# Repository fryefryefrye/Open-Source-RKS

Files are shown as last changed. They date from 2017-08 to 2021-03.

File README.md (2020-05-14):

# Open-Source-RKS
### What is a RKS system
RKS as the Remote keyless system. It's a proximity system that is triggered if a key is within a certain distance. <br> 
Widely used in modern vehicles. It's very convenient to Entry your car when you have RKS system. <br> 
You do not need take out of your key, just walk to your car with the key in your pocket, then you can open the door.<br>

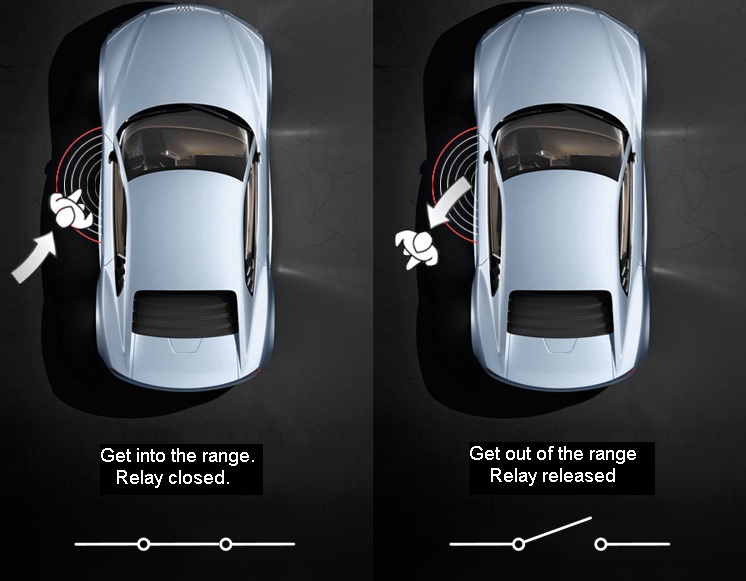
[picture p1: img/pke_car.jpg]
 <br>

<br> But do you want open the door of your home without take out your keys? Or equipment RKS to your old car?<br> 
I've found a solution that every electronic fans can make a RKS system at home in a very cheap price.<br> 
An iPhone without any app can be used as a wireless tag<br> 
Arduino based Controller can make you to use this system in any application if you like.<br>  
You can submit a issue or mail to me if you have any question.<br> 
<br>
## New update: Use your iPhone as a Tag.
### iPhone:
When IOS is enabling with continuity service, it will always sending BLE advertising to let other IOS device to know. But the Bluetooth MAC Address is random and changed every 15 minutes. <br>
With my another project, you can decode the random address and determined if this random address belongs to your phone.<br>
https://github.com/fryefryefrye/Decoding-Random-Bluetooth-Address/<br>
### Android:
Use "nRF Connect" APP, you can send BLE advertising with custom data.A name can be set in the advertising.<br>

## Hardware used:

iPhone; ESP32 Board; Arduino Board; nRF24L01 module

## Get IRK of your iPhone
If the IRK of an IOS device is known, the random Bluetooth address can be determined if it belongs to this device. <br>
### Use an ESP32 board and download with “iPhone/get_irk” project. It will start a BLE service. <br>
Pay attention on following settings.<br>
 <br>
### Use your iPhone install with “LightBlue” APP, find the “ESP_BLE_SECURITY” service, and connect it, the IRK will be print out. <br>
 <br>

## Receiver / Monitor BLE advertising with nRF24L01
With the help of the following project, we can Monitor BLE advertising with very cheap nRF24L01 module<br>
https://github.com/Pranavgulati/RF24BLE<br>
https://github.com/nRF24/RF24<br>
Install above two library into Arduino.<br>
Fill the IRK into the “iPhone/ReceiverController” project..<br>
Download “iPhone/ReceiverController” project into a Arduino nano board, you can Monitor BLE advertising and determine if the MAC address in the air is belong to your iPhone.<br><br>
These is only one key function you need to call to check MAC address. Everything needed for this function is in key.h file.You can use it in your other project.<br>
BOOLEAN btm_ble_addr_resolvable(BD_ADDR rpa, esp_bt_octet16_t irk)<br><br>

You can build the Arduino based BLE Monitor Just connect nRF24L01 module with Arduino follow the table.<br>

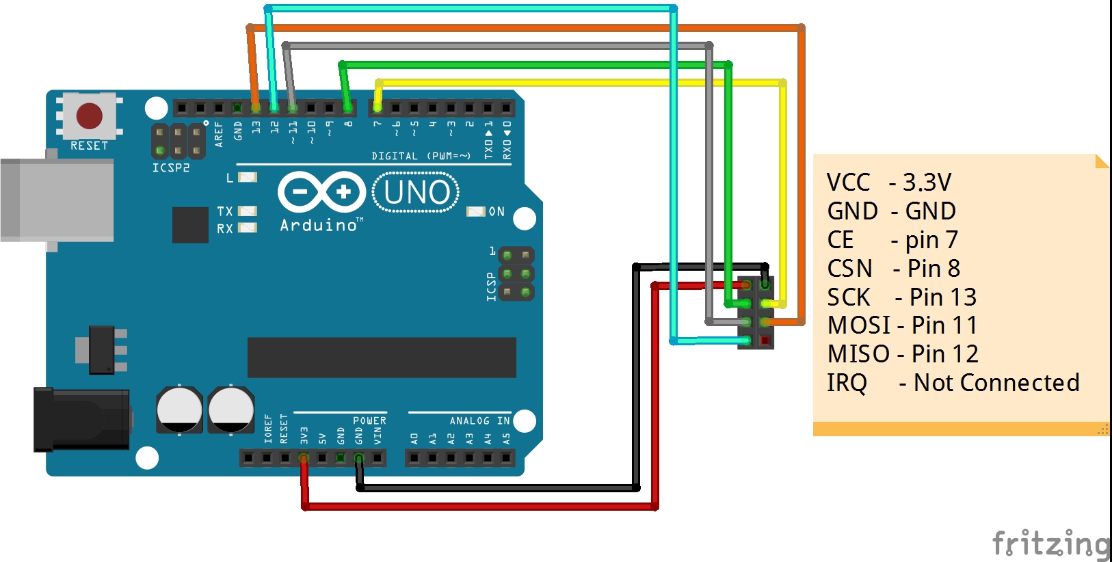
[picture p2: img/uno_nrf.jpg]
 <br>

 <br>

When you are OK to this stage, if you are walking to your reciver with your iPhone, the arduino will know you are coming.<br>
And you can write your applaction code. Like close a relay to open a door.<br>

## Old version: Released on 2016. Use Independent Wireless Tag.

### A very simple wireless Key. 

nRF24LE1 module and CR2032 battery are the only thing to make a key for RKS system. <br>
nRF24LE1 is Ultra-low Power Wireless System On-Chip Solution.<br>
An 8051 compatible MCU is attached in it. So one chip is enough.<br>
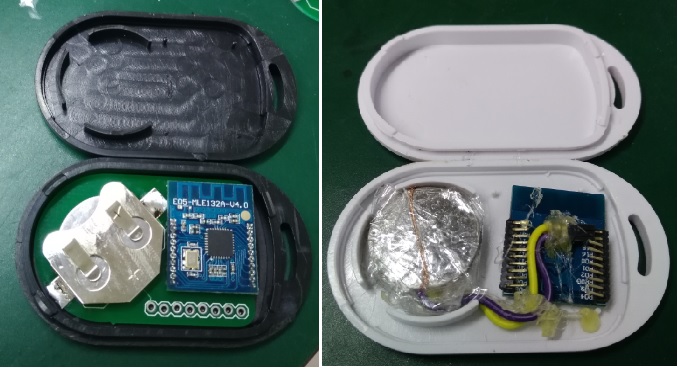
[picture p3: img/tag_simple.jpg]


### Arduino based Controller

An Arduino equipment with a nRF24L01 module, can receive the data from the key nearby.<br> 
Arduino based Controller is very easy to program, and you can make any application if you wish base on this RKS system.<br> 
In This example, a relay will be used as the output. <br> 
When key goes close in about 2 meters, the relay closed.<br> 
When key goes far away, the relay will be disconnect.<br> 
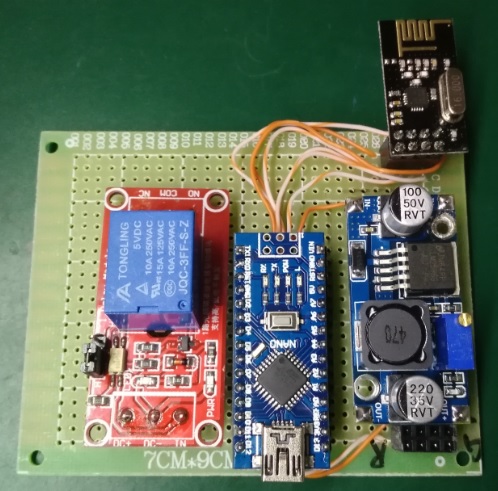
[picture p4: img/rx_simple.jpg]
.

### How they made?
* Make the Tag/Key/Transmitter

First you need program the nRF24LE1 use a Programmer.<br>
After that, just connect 2 cables from battery to power on the nRF24LE1 module is OK.<br>
All the needles on the module can be cut to short to fit in the thin case.<br>
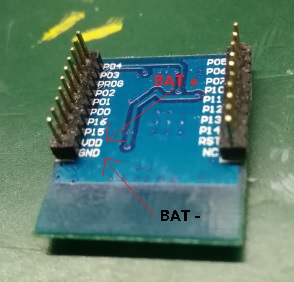
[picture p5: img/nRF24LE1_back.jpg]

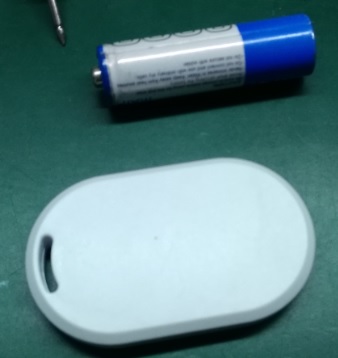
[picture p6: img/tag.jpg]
.<br>

* Make the Controller/Receiver

You can build the Arduino based Controller whatever you like. Just connect nRF24L01 module with Arduino follow the table.<br>

| PIN  | NRF24L01|Arduino UNO/NANO|Mega1280/2560|
| --- | ---| ---| ---|
|  1  |  GND  |  GND  |  GND  |
|  2  |  VCC  |  3.3V  |  3.3V  |
|  3  |  CE |  digIO 7  |  digIO 7  |
|  4  |  CSN  |  digIO 8  |  digIO 8  |
|  5  |  SCK |  digIO 13  |  digIO 52  |
|  6  |  MOSI  |  digIO 11  |  digIO 51  |
|  7  |  MISO  | digIO 12  |  digIO 50  |
|  8  |  IRQ  |  -  |-|
<br> 



<br>
This is combination I used in debug stage.<br> 

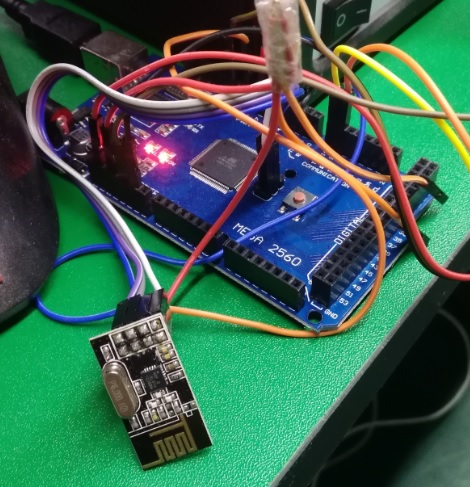
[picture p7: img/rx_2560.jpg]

<br> 
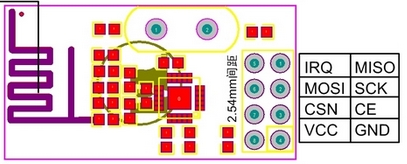
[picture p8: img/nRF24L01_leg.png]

<br>
The PCB for Controller is on the way, I will update soon.<br>

## Technical details

### Frequency hopping

The key, as an Active RFID Tag, will transmit its ID and the volt of the battery 3 times every second in 3 different channels.<br> 
The Controller, as the receiver, will listening on these 3 different channels, one channel for one second.<br> 
This will make the system more anti-interference.<br> 

### Power Consumption of the Tag

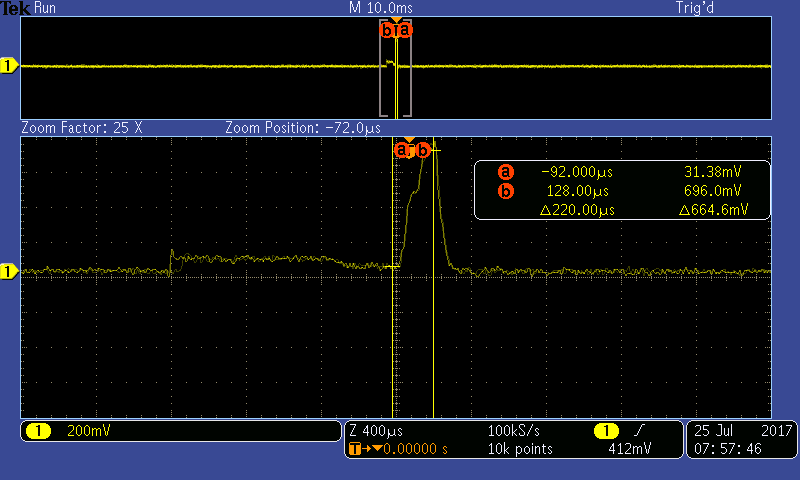
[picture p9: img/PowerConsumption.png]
<br> 

The above picture is Current sampling with a 47 Ohm resistor.<br> 

For every time of transmit. Power consumption can be estimated as:  <br> 
0.7v\*47Ohm = 32.9mA<br> 
Duration for 0.3ms <br> <br> 
Capacity of a CR2032 battery is 200 mAh.<br> 
In This example, data was transmit 3 times in every second. <br> 
Estimated life days = (200/(32.9\*(0.0003/3600)))/3/3600/24 = 281 days <br> 

## Hardware used in this project

* Tag/Key/Transmitter

### nRF24LE1 module
Reference price € 4.00<br> 
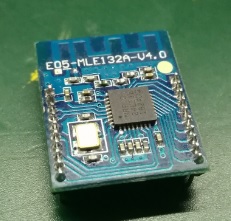
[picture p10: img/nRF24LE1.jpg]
<br> 

### Programmer for nRF24LE1
Reference price € 15.00<br> 
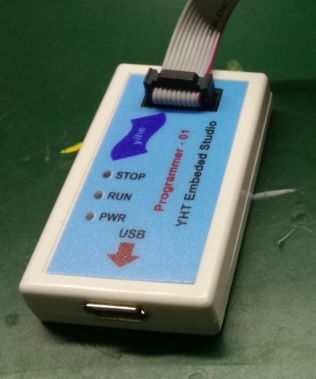
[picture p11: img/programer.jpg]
<br> 

### nRF24LE1 adapter.
Reference price € 5.00<br> 
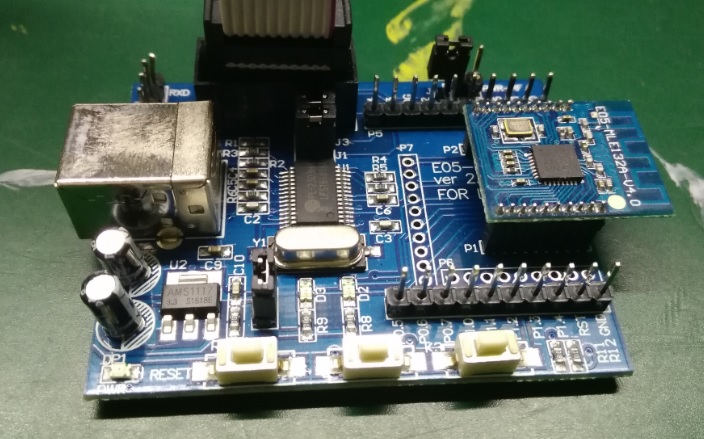
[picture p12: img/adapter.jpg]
<br> 

### CR2032 battery
Reference price € 1.00<br> 
<br> 

### Plastic case of the key
Reference price € 1.00<br> 
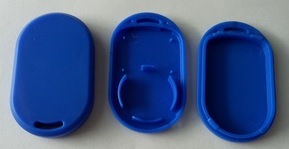
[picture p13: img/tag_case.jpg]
<br> 

### PCB of the key
Reference price € 1.00<br> 
Send the file PCB\Files_for_Factory_made\tag.cam to PCB factory, they can make it for you.<br> 
A programmer interface is placed on the PCB, you can also program the nRF24LE1 with this port after the module have been soldered on the PCB.<br> 
Or you can use any method you can do to connect the module with battery.<br> 
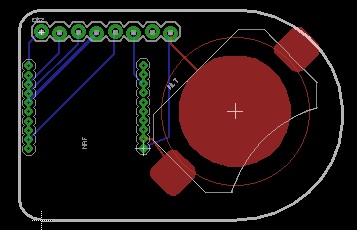
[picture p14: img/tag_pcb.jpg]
<br> 

### Battery holder in the key
Reference price € 1.00<br> 
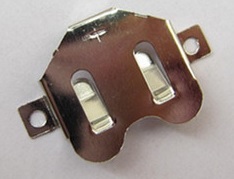
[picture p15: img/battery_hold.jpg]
<br> 

* Controller/Receiver

### Arduino
Reference price € 5.00<br> 
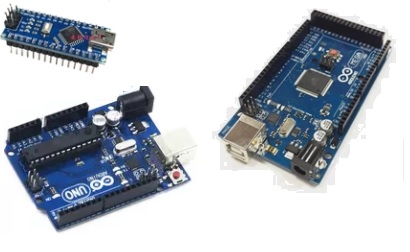
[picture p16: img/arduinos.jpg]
<br> 

### nRF24L01 module
Reference price € 2.00<br> 
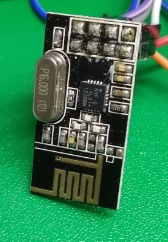
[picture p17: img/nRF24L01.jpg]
<br> 

### Integrated PCB of Controller
Reference price € 2.00<br> 
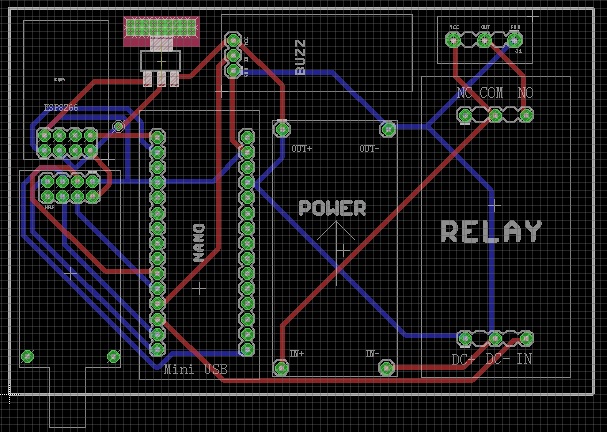
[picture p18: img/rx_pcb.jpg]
<br> 

### Buzz module
Reference price € 1.00<br> 
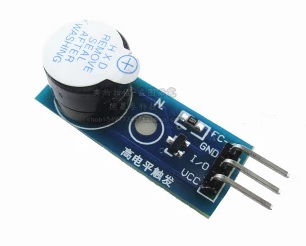
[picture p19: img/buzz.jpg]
<br> 

### Relay module
Reference price € 1.00<br> 
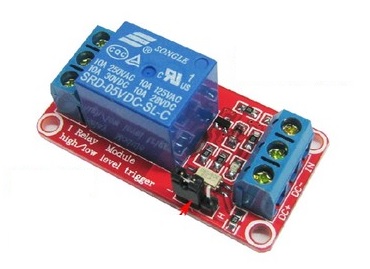
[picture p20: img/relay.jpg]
<br> 

### nRF24L01+PA module
Reference price € 4.00<br> 
A more powerful nRF24L01+PA module can get longer range and has External antenna interface. It has a compatible interface with nRF24L01 module<br> 
But it need more power on 3.3v, so a AMS1117-3.3v can be used to power this module.<br> 
<br> 

### DC-DC Converter
Reference price € 1.00<br> 
Most of cars, door locking system are using 12v. So a DC-DC Converter is needed here to power the Arduino with 5v. <br>
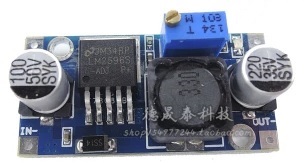
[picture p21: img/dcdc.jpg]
<br> 

## Video

## Draft

After check the ID of the key, it will drive the relay to Unlock the door for you.<br> 
When the key is get a little far away, the relay will release and the door will be locked.<br> 
You can also equipment with some power system to open the door automatically.<br>

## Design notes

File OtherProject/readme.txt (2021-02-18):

超简单DIY--制作自动授时64*32LED单色大屏时钟（开源）

落叶风大侠的WiFi LED彩屏天气万年历时钟，确实非常不错，但是门槛太高了，很多人想做，但是力不从心啊。

我这边发布一个能够让更多人能够做出来的大屏时钟，有以下优点。

1：程序简单，只有一个Arduino工程，插上USB即可下载。
2：硬件简单，只需要两个元件，焊接10来根线，无需电路板。
3：成本便宜，LED板全新价格也就30元，再加一块10元的ESP8266 D1板就够了。
3：联网能力，ESP8266有联网能力，我开源的程序，已经做好了时间同步。以后可以继续扩展天气预报等功能。
4：中文显示，我开源的程序，已经集成了16*16中文字库，可以直接用UTF-8编码显示。显示天气，万年历等超级方便。
5：OTA能力，除了第一次需要用USB下载，以后可以使用WiFi下载程序了，无需把墙上的时钟拿下来。

所需的两个元件，淘宝采购：
这种LED屏有红色单色的，也有红绿双色的。但是ESP8266的IO口有限，我只能搞定一种颜色。如果买红绿双色，只能用改变接线的方式，永久性的改变颜色，可以显示绿色，也可以显示橙色。

打开源代码，找到如下部分：
#define RowA D8    	//行信号,驱动138  
#define RowB D7
#define RowC D6
#define RowD D5
#define STB D2         //595 刷新显示  SS  
#define CLK D1         //时钟    SCK  
#define OE D0 			//  使能  
#define R1 D4          //上半屏列信号输出    
#define R2 D3          //下半屏列信号输出    

照此定义，把LED屏和ESP8266 D1 板焊在一起。另外把5v供电线也给焊上。板上插一根USB线备用。

硬件完工，下面搞软件：

Arduino的开发环境，下载下来后，需要在“开发板管理器”里面加入ESP8266的支持。
另外在“库管理器中”下载一个“u8g2”这是一个包含中文字库的显示屏驱动。

最后一步，修改源代码中的wifi名和密码，然后通过USB下载，就搞定啦。

源代码在此：
https://github.com/fryefryefrye/Open-Source-RKS/tree/master/OtherProject/clock

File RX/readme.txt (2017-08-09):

This is an arduino project.

It can be download to:
Arduino 2560
Arduino nano
Arduino uno
......

RX.ino

It's a very basic application. If it get data from Tag, the relay of the door will closed.

RX_315.ino

It's a bit advanced application. If it get data from Tag, it will send out remote control single like your car key, to Ulock or Lock your car.
A RF_TX module of 433/315 Mhz is needed. Also you must know protocol of your car key.

rx_web.ino

It's another bit advanced application. It works like the first door controller, but it will record all entry log with the  volt of the battery.
With a ESP8266, it also works as a web server, you can open the address of the controller, check the logs.

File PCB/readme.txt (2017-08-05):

PCB was made by EAGLE-7.6.0.
Files in following foler can be send to Factory to make the PCB.
\PCB\Files_for_Factory_made

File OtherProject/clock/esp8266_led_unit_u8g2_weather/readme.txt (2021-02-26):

[Arduino] 超简单DIY~制作64*32 LED单色大屏天气预报（开源） 

上次发的大屏时钟。

[Arduino] 超简单DIY~制作自动授时64*32 LED单色大屏时钟（开源） 
https://www.mydigit.cn/forum.php?mod=viewthread&tid=235844

代码内置了中文字库，但是还没用上，今天折腾了一下，把天气预报的部分也搞好了，让新手也能简单上路，搞个带天气预报的时钟。

本次硬件还是和上次的一样，只做了些软件的修改。
需要自己去"心知天气"申请一个帐号，获得api-key。然后填到代码开头的相应位置。注意后面城市名，我写的是nanjing，个人自己修改好。有重名的话，去心知天气网站找到自己城市的代号填上去，更准确。

我写的屏幕布局只是个例子，自己可以随意修改。在代码的最后部分。那些都是在屏幕上打印字符串的函数，其中两个数字参数就是屏幕的x，y坐标，根据自己需要修改试验就行了。

在我家的墙上挂的是这个，只是很久以前做的，不管是硬件还是软件都很烂，就不分享了。怕麻烦的同学直接做两个，并排放就可以了。

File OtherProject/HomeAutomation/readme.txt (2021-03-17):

介绍我家的智能家居系统（原理细节详细介绍，尽量部分关键部分开源）

我家这套智能家居系统已经运行了很多年了，自我感觉不错，给大家分享一下。
也是断断续续开发了很多年，一下子不可能讲的很清楚，有兴趣的同学可以提问，我继续回答。

早年买了一些所谓的智能家居硬件设备，最后得到的是手机里一大堆APP，以及薛定谔状态的可用性。最后决定全部自己开发。

现在这套系统的优点：
1：全部自己开发，需要新功能，实现新想法，只要是可行的，就能做出来。
2：大部分功能通过局域网实现，不依赖互联网。只要家里有电，就能正常运行大部分功能（外网控制除外）
3：控制界面只有一个，一眼看清所有设备状态，一键即可控制所需设备，无需在一堆APP中，一大堆页面中翻来翻去。

整套系统主要结构如下：

1：用ESP8266作为节点，每秒发一个UDP包到树莓派服务器，包含节点采集到的数据和状态（比如：温度，湿度，灯已开，灯已关）。
2：树莓派服务器收到节点更新后，回复一个UDP命令包，包含发送给节点的控制命令（比如：开灯，关灯），并缓存节点的IP地址信息。
3：树莓派另开web服务，手机电脑均可访问，可以查看状态，也可以控制，在家通过局域网访问，不依赖互联网，在外需要做一个端口映射（申请公网IP）。
4：收到web的控制命令后，立即给节点发送命令UDP包（之前已经缓存了节点IP信息），可以做到灯一按就亮，几乎无延时。

控制界面是这样的：

控制界面的实现原理（使用Ajax更新网页里的部分文字）：
上图所示的控制界面是一个html文件，只需要加载一次。但是表格中的数据和状态都是每秒使用Ajax更新的。
流程大概是这样
a）浏览器请求 http://192.168.0.17/index   树莓派服务器直接返回一个html文件
b）html文件里面有脚本，每秒执行一次，发起请求  http://192.168.0.17/update
c）树莓派返回一串用“,”隔开的字符串。脚本会按照“,”分割，形成一个字符串数组。
d）把这个数组填个表格的相应部分。

这是html文件的一个简单的例子，我用来显示天气预报的。
https://github.com/fryefryefrye/Open-Source-RKS/tree/master/OtherProject/HomeAutomation/weatherindex.html

树莓派服务器实现原理（web服务）：

上一段已经介绍了如何使用Ajax更新网页里的部分文字，其中重要的一点就是服务器需要自动生成一串用“,”隔开的字符串。
这个就需要在树莓派上编程实现。
由于我不喜欢使用现成的web服务软件，我就自己实现了一个最简单的web服务器。
流程大概是这样
a）创建一个socket，在80端口上监听。
b）连接建立之后，一般会收到一个类似“GET /index HTTP/1.1”的请求。
c) 根据请求内容，给予适当的回复，在回复实际内容之前，发送一个http回复的head就行了
const char HttpResponseHeadSimple[]   ="HTTP/1.1 200 OK\r\nContent-Type: text/html\r\n\r\n";
d）上面那个头部，最后两个回车之后，就可以发送实际数据了，不管是一个html文件，还是“,”隔开的字符串，都可以。
e）发完就可以关闭socket,等待下一个连接请求。

树莓派服务器实现原理（UDP数据交换）：
为了定义节点与服务器交换的数据格式，我写了一个共用h文件，即被Arduino节点的程序包含，也被服务器的程序包含。
这个h文件里定义数据格式，例子如下。
struct tMeterData
{
	unsigned long DataType; //data type = 5
	unsigned long Mac[6];
	unsigned long Power;		//xx.xxxx W
	unsigned long TotalEnergy;		//xxxxxx.xx kWh
	unsigned long Volt;			//xxx.x v
	unsigned long Current;		//xxx.xxx A

};

struct tMeterCommand
{
	unsigned long Triger; 
	unsigned long On
};

这是一个交流电功率计的数据格式的例子，所有的数据都是用的4字节长整型，以免不同的平台的字节序问题。
上传数据的第一组是数据类型，用来检测是哪一种设备发来的，其他的就是数据更新。
下发的命令是每秒都会回复的，当作心跳包。但是没有实际操作请求的时候，triger = false。
如果真的要操作，就设为True，表示这是一个需要执行的命令，节点就会根据下发的数据执行相应的操作。

不同功能的节点，其实很多，我介绍几个大家比较能用的着的（待续）：

1：房间灯光控制器

2：房间空调控制器

3：用电功率监视器

4：挂在家里的天气预报/时钟

5：电动车充电控制器

不同功能的界面：

1：家门口控制器

2：挂在公司的天气预报

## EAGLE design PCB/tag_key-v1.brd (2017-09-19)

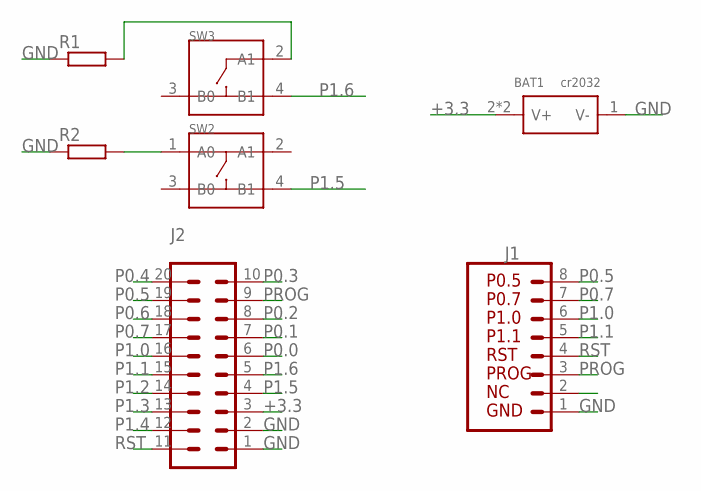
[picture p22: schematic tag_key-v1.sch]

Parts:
BAT1: cr2032; SEEED-OPL-CONNECTOR_BAT2P-20.32-CR2032
J1: SPARKFUN-CONNECTORS_CONN_08"; SPARKFUN-CONNECTORS_1X08
J2: SPARKFUN-CONNECTORS_CONN_11_1.27MM; SPARKFUN-CONNECTORS_1X11-1.27MM
R1, R2: RESISTOR_R-EU_M0805; RESISTOR_M0805
SW2: SEEED-OPL-SWITCH_SMD-BUTTON(4P-6.0X6.0X7.5MM); SEEED-OPL-SWITCH_SW4-SMD-4.5-6.0X6.0X7.5MM
SW3: SEEED-OPL-SWITCH_SMD-BUTTON(4P-6.0X6.0X3LEGM); SEEED-OPL-SWITCH_SW4-SMD-4.5-6.0X6.0_3LEG

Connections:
+3.3: BAT1.2 (V+), BAT1.3 (V+), J2.3
GND: BAT1.1 (V-), J1.1, J2.1, J2.2, R1.1, R2.1
unnamed: R2.2, SW2.1 (A0)
unnamed: R1.2, SW3.2 (A1)
P0.0: J2.6
P0.1: J2.7
P0.2: J2.8
P0.3: J2.10
P0.4: J2.20 (11)
P0.5: J1.8, J2.19 (12)
P0.6: J2.18 (13)
P0.7: J1.7, J2.17 (14)
P1.0: J1.6, J2.16 (15)
P1.1: J1.5, J2.15 (16)
P1.2: J2.14 (17)
P1.3: J2.13 (18)
P1.4: J2.12 (19)
P1.5: J2.4, SW2.4 (B1)
P1.6: J2.5, SW3.4 (B1)
PROG: J1.3, J2.9
RST: J1.4, J2.11 (20)

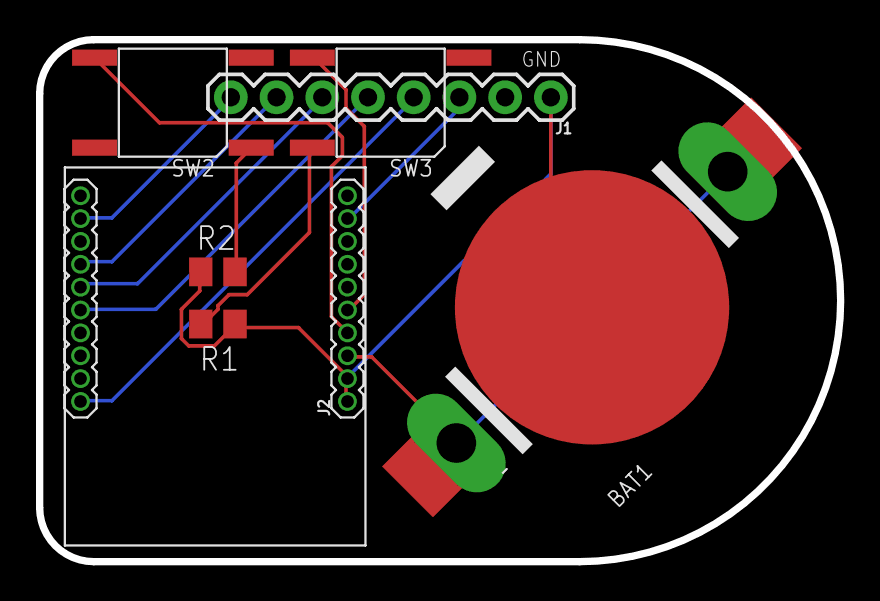
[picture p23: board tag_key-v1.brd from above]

Board: 2 copper layers, 44.5 x 29.0 mm, 7 parts (0 on the bottom side), 12 nets.

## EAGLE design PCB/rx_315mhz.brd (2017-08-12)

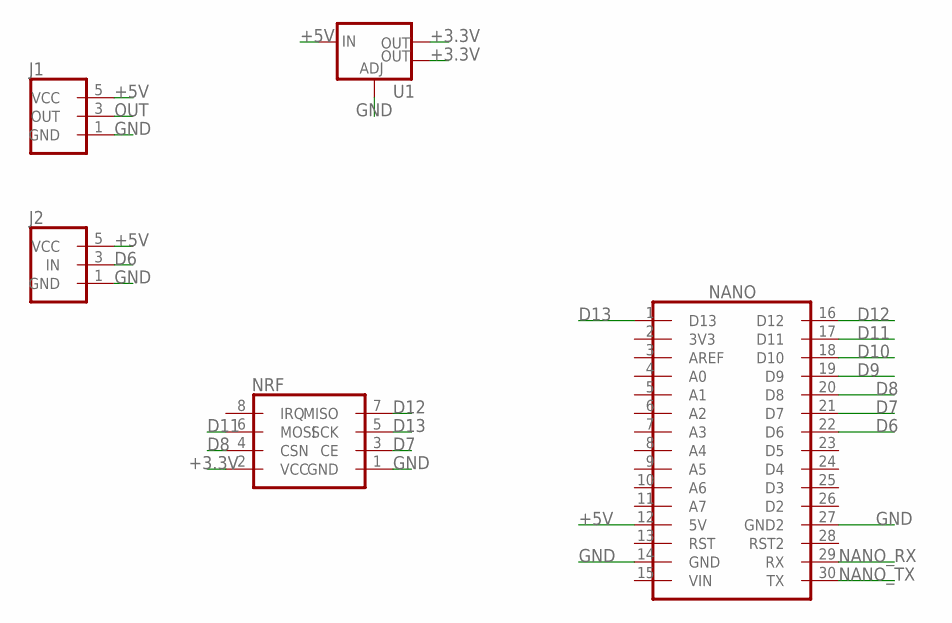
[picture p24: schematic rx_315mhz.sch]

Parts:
J1: OUT_HEAD_3BIG; OUT_HEAD_3_BIG
J2: 315MHZ_TX
NANO: ARDUINO_NANO
NRF: NRF24L01_MODULE; NRF24L01
U1: V_REG_LM1117SOT223; SOT223

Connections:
+3.3V: NRF.2 (VCC), U1.2 (OUT), U1.4 (OUT)
+5V: J1.5 (VCC), J2.5 (VCC), NANO.12 (5V), U1.3 (IN)
D6: J2.3 (IN), NANO.22 (D6)
D7: NANO.21 (D7), NRF.3 (CE)
D8: NANO.20 (D8), NRF.4 (CSN)
D9: NANO.19 (D9)
D10: NANO.18 (D10)
D11: NANO.17 (D11), NRF.6 (MOSI)
D12: NANO.16 (D12), NRF.7 (MISO)
D13: NANO.1 (D13), NRF.5 (SCK)
GND: J1.1 (GND), J2.1 (GND), NANO.14 (GND), NANO.27 (GND2), NRF.1 (GND), U1.1 (ADJ)
NANO_RX: NANO.29 (RX)
NANO_TX: NANO.30 (TX)
OUT: J1.3 (OUT)

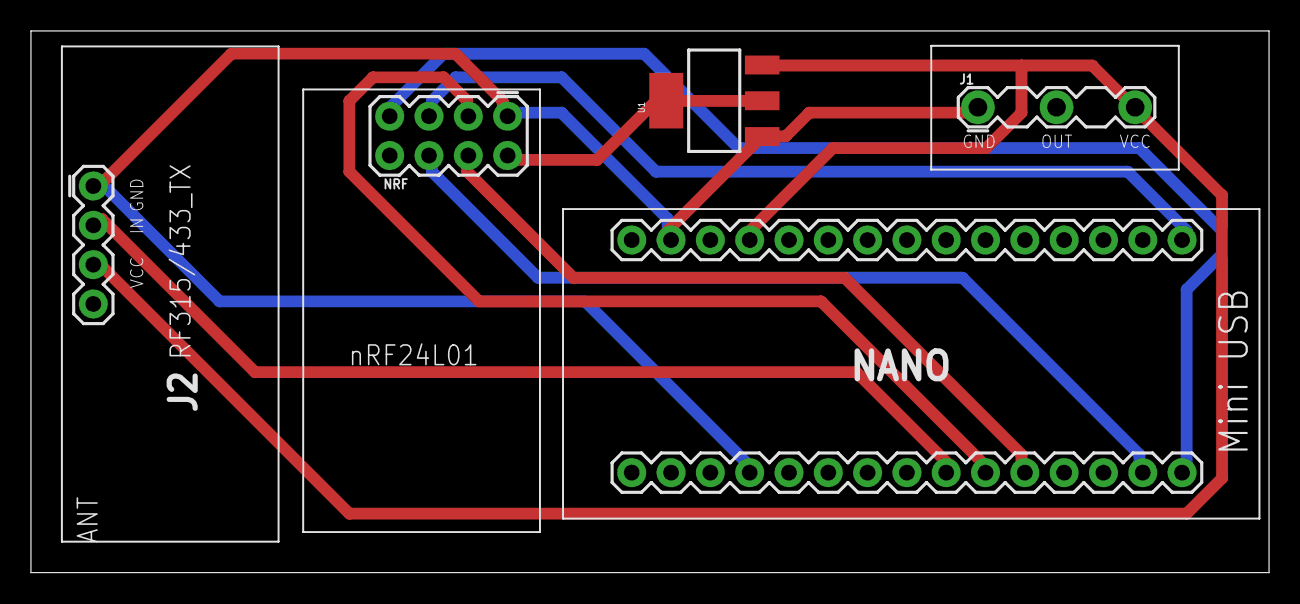
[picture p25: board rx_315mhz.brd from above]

Board: 2 copper layers, 80.0 x 35.0 mm, 5 parts (0 on the bottom side), 9 nets.

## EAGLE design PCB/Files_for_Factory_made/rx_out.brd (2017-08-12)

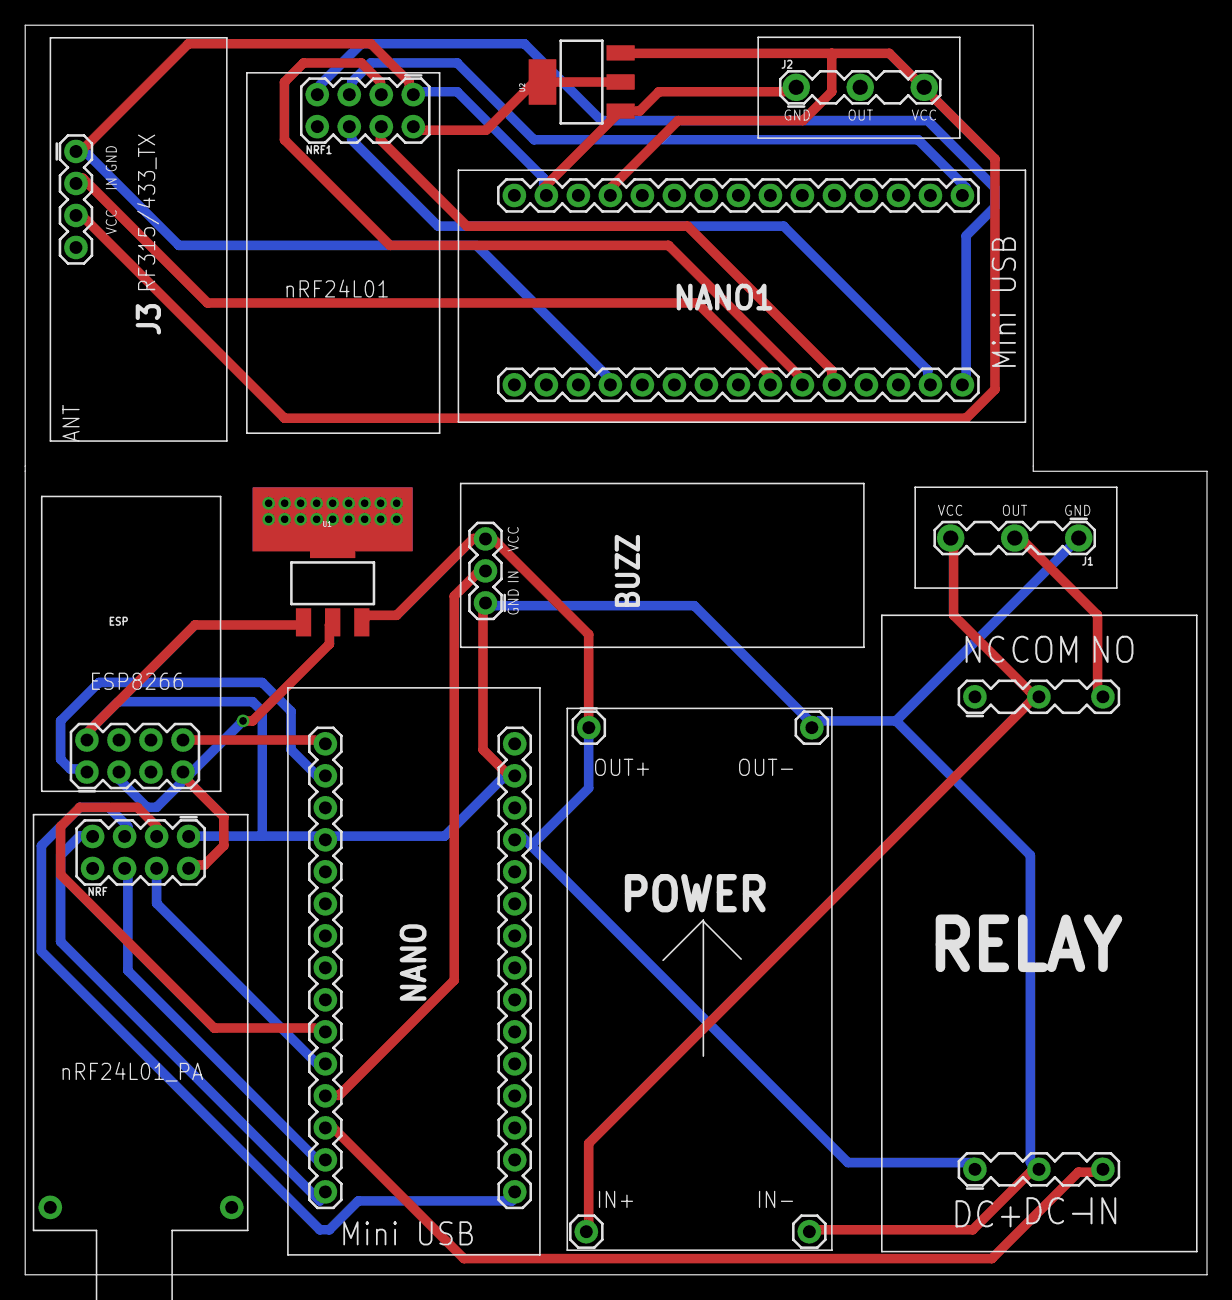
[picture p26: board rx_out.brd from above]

Board: 2 copper layers, 93.8 x 99.2 mm, 13 parts (0 on the bottom side), 23 nets.

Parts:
BUZZ: BUZZ_MODULE
ESP: ESP8266
J1, J2: OUT_HEAD_3_BIG
J3: 315MHZ_TX
NANO, NANO1: ARDUINO_NANO
NRF: NRF24L01_PA
NRF1: NRF24L01
POWER: POWER_REDUCE
RELAY: RELAY_MODULE
U1, U2: SOT223

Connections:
+3.3V: ESP.3, ESP.7, NRF.2, U1.2, U1.4
+3.3V1: NRF1.2, U2.2, U2.4
+5V: BUZZ.5, NANO.12, POWER.1, RELAY.1, U1.3
+5V1: J2.5, J3.5, NANO1.12, U2.3
+12V: J1.5, POWER.3, RELAY.5
D1: NANO1.17, NRF1.6
D2: NANO1.20, NRF1.4
D3: NANO1.1, NRF1.5
D4: NANO1.21, NRF1.3
D5: NANO1.16, NRF1.7
D7: NANO.21, NRF.3
D8: NANO.20, NRF.4
D9: BUZZ.3, NANO.19
D10: NANO.18, RELAY.3
D11: NANO.17, NRF.6
D12: NANO.16, NRF.7
D13: NANO.1, NRF.5
D15: J3.3, NANO1.22
GND: BUZZ.1, ESP.2, J1.1, NANO.14, NANO.27, NRF.1, POWER.2, POWER.4, RELAY.2, U1.1
GND1: J2.1, J3.1, NANO1.14, NANO1.27, NRF1.1, U2.1
NANO_RX: ESP.1, NANO.29
NANO_TX: ESP.8, NANO.30
OUT: J1.3, RELAY.6

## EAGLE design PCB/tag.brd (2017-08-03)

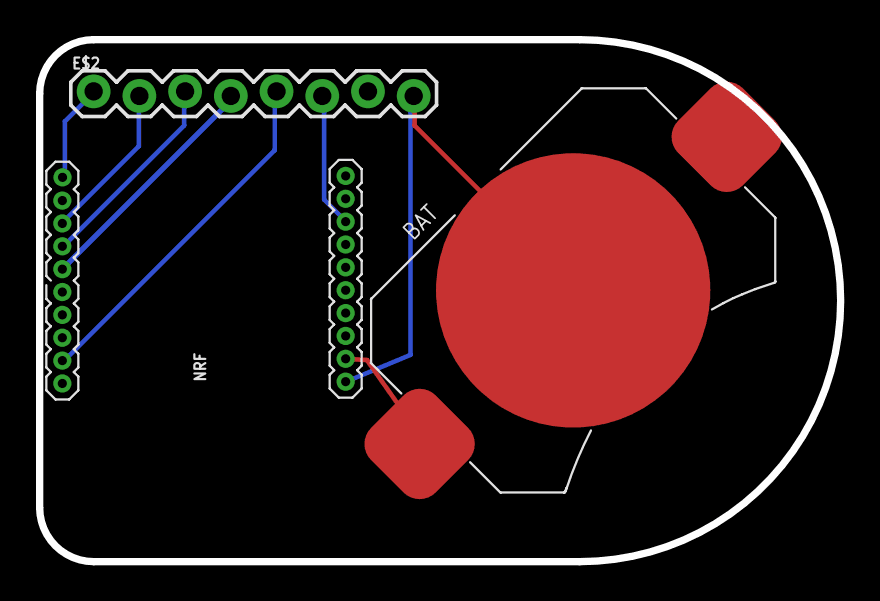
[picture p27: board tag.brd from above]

Board: 2 copper layers, 44.5 x 29.0 mm, 3 parts (0 on the bottom side), 8 nets.

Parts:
BAT: BAT2P-SMD-20.32-CR2032
E$2: 1X08_LOCK
NRF: 1X11-1.27MM

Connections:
S$1: BAT.V-, E$2.8, NRF.1
S$2: BAT.V1, NRF.2
S$3: E$2.4, NRF.14
S$5: E$2.3, NRF.16
S$8: E$2.6, NRF.8
S$12: E$2.5, NRF.19
S$14: E$2.2, NRF.18
S$15: E$2.1, NRF.11

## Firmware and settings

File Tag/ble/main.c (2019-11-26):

#include <reg24le1.h>
#include <stdint.h>
#include <stdbool.h>
#include "hal_nrf.h"
#include "hal_nrf_hw.h"
#include "hal_clk.h"
#include "hal_rtc.h"
#include "hal_delay.h"
#include "hal_adc.h"
#include "hal_wdog.h"
#include "hal_uart.h"
#include "string.h"


/*************************user modify settings****************************/
#define  TAG_ID 2


#define  TAG_TIME				10530+64*TAG_ID		//sleep time£º10530=0.3s;	32768=1s
#define  ADC_TIME				10800		//volt of BAT,   every =   ADC_TIME*TAG_TIME
#define  TX_PAYLOAD_LEN			6        	// data length
#define  TX_PACKET_LEN			TX_PAYLOAD_LEN + 16        	// data length
#define  TX_CH_NUMBER			3        	// data length       

#define  RF_POWER 		 HAL_NRF_0DBM
//HAL_NRF_18DBM,          /**< Output power set to -18dBm */
//HAL_NRF_12DBM,          /**< Output power set to -12dBm */
//HAL_NRF_6DBM,           /**< Output power set to -6dBm  */
//HAL_NRF_0DBM            /**< Output power set to 0dBm   */

/******************************************************************************/


//#define  S1    P15  // Key S1
//#define  S2    P16  // Key S2

//// The MAC address of the beacon
#define MY_MAC_0  0x60
#define MY_MAC_1  0x59
#define MY_MAC_2  0x48
#define MY_MAC_3  0x47
#define MY_MAC_4  0x46
#define MY_MAC_5  0x45

#define ANDROID		 0x42
#define IPHONE		0x40

/* Watchdog*/
#define USE_WDT   1
#define WDT_TIME  256  //2S


uint8_t   CellVoltageH;
uint8_t   CellVoltageL;
xdata bool  radio_busy;
xdata uint8_t  TxPayload[TX_PAYLOAD_LEN];
uint16_t PipeAndLen;
uint8_t CurrCH = 0;


void PrintInt16(uint16_t Counter);
void UART0_SendStr( char* str );

//xdata uint8_t _packet[TX_PACKET_LEN] = {0xBA,0x1C,0x54,0x60,0xBB,0x85,0x53,0xF3,0xC3,0xEB,0x03,0x82,0xFB,0xBA,0xBB,0xC7,0x71,0x7E,0x2D,0x01}; //maximum size of payload handled by nrf24L01 is 32
xdata uint8_t _packet_coded[TX_CH_NUMBER][TX_PACKET_LEN] = {{0xF3,0xBB,0xEC,0x1F,0xA6,0x0F,0x0C,0xA7,0xEE,0x0C,0x28,0xB2,0x96,0x6E,0x5F,0x07,0x42,0x1F,0x82,0x85}  //Len = 20 ch = 0Start LE advertizing
,{0x29,0x53,0x24,0x9E,0x80,0x91,0xED,0x5B,0x98,0x25,0x55,0xE2,0x21,0xF2,0xF3,0xC6,0xF7,0xCE,0x13,0x87}  //Len = 20 ch = 1Start LE advertizing
,{0xBA,0x1C,0x54,0x60,0xBB,0x85,0x53,0xF3,0xC3,0xEB,0x03,0x82,0xFB,0x1A,0x3B,0x47,0xD1,0x50,0xF2,0x7B}};  //Len = 20 ch = 2Start LE advertizing

uint8_t _length = 0; //length of packet filled
uint8_t _dataFieldStartPoint = 0;
xdata uint8_t chRf[] = {2,26,80} ; 
xdata uint8_t chLe[] = {37,38,39} ;

#define crc_mul 0x1021
uint16_t cal_crc(unsigned char *ptr, unsigned char len)
{
	unsigned char i;
	unsigned int crc=0;
	while(len-- != 0)
	{
		for(i=0x80; i!=0; i>>=1)
		{
			if((crc&0x8000)!=0)
			{
				crc<<=1;
				crc^=(crc_mul);
			}else{
				crc<<=1;
			}
			if((*ptr&i)!=0)
			{
				crc ^= (crc_mul);
			}
		}
		ptr ++;
	}
//	UART0_SendStr("crc:");
//	PrintInt16(crc);
//	UART0_SendStr("\r\n");
	return (crc);
}

void fill_crc(unsigned char *ptr, unsigned char stru_len)
{
	uint16_t * pSum = ((uint32_t*)(ptr+stru_len-2));
	*pSum = cal_crc(ptr,stru_len-2);
}

uint8_t  reverseBits(uint8_t input)
{
		// reverse the bit order in a single byte
		uint8_t temp = 0;
		if (input & 0x80) temp |= 0x01;
		if (input & 0x40) temp |= 0x02;
		if (input & 0x20) temp |= 0x04;
		if (input & 0x10) temp |= 0x08;
		if (input & 0x08) temp |= 0x10;
		if (input & 0x04) temp |= 0x20;
		if (input & 0x02) temp |= 0x40;
		if (input & 0x01) temp |= 0x80;
		return temp;
}
uint8_t  bleWhitenStart(uint8_t chan){
	//use left shifted one
	return reverseBits(chan) | 2;
}

void setPhone(uint8_t phone_type)
{
	//byte no.0 PDU
	uint8_t i;
	for(i=0; i<TX_CH_NUMBER; i++)
	{
		_packet_coded[i][0] = phone_type;	
	}
}
void setMAC(uint8_t m0, uint8_t m1, uint8_t m2, uint8_t m3, uint8_t m4, uint8_t m5)
{
	uint8_t i;
	for(i=0; i<TX_CH_NUMBER; i++)
	{
		//length of payload is entered in byte no.1
		_length = 2;
		_packet_coded[i][_length++] = m0;
		_packet_coded[i][_length++] = m1;
		_packet_coded[i][_length++] = m2;
		_packet_coded[i][_length++] = m3;
		_packet_coded[i][_length++] = m4;
		_packet_coded[i][_length++] = m5;
		//length should be 8 by now
		//flags (LE-only, limited discovery mode)
		_packet_coded[i][_length++] = 2;    //flag length
		_packet_coded[i][_length++] = 0x01; //data type
		_packet_coded[i][_length++] = 0x05; //actual flag
	}
}

void setData(void* Data,uint8_t dataLen)
{
	uint8_t i,j;
	uint8_t* current;
	_dataFieldStartPoint = (_dataFieldStartPoint==0?_length:_dataFieldStartPoint);


	for(j=0; j<TX_CH_NUMBER; j++)
	{
		_length = _dataFieldStartPoint;
		current = (uint8_t*)(Data);
	
		_packet_coded[j][_length++] = dataLen +1;
		_packet_coded[j][_length++] = 0xFF;//data type
		for (i = 0; i < dataLen; i++){
			_packet_coded[j][_length++] = *(current);
			current++;
		}
		//CRC is appended to the data
		//CRC starting val 0x555555 acc. to spec
		_packet_coded[j][_length++] = 0x55;
		_packet_coded[j][_length++] = 0x55;
		_packet_coded[j][_length++] = 0x55;
	}
}

void BLEcrc(const uint8_t* Data, uint8_t dataLen, uint8_t* outputCRC){
	// calculating the CRC based on a LFSR
	uint8_t i, temp, tempData;

	while (dataLen--){
		tempData = *Data++;
		for (i = 0; i < 8; i++, tempData >>= 1){
			temp = outputCRC[0] >> 7;
			
			outputCRC[0] <<= 1;
			if (outputCRC[1] & 0x80){ outputCRC[0] |= 1; }
			outputCRC[1] <<= 1;
			if (outputCRC[2] & 0x80){ outputCRC[1] |= 1; }
			outputCRC[2] <<= 1;

			if (temp != (tempData & 1)){
				outputCRC[2] ^= 0x5B;
				outputCRC[1] ^= 0x06;
			}
		}
	}
}

void bleWhiten(uint8_t* Data, uint8_t len, uint8_t whitenCoeff){
	// Implementing whitening with LFSR
	uint8_t  m;
	while (len--){
		for (m = 1; m; m <<= 1){
			if (whitenCoeff & 0x80){
				whitenCoeff ^= 0x11;
				(*Data) ^= m;
			}
			whitenCoeff <<= 1;
		}
		Data++;
	}
}

void blePacketEncode(uint8_t* packet, uint8_t len, uint8_t chan){
	// Assemble the packet to be transmitted
	// Packet length includes pre-populated crc 
	uint8_t i, dataLen = len - 3;
	BLEcrc(packet, dataLen, packet + dataLen);
	for (i = 0; i < 3; i++, dataLen++)
		packet[dataLen] = reverseBits(packet[dataLen]);
	bleWhiten(packet, len, bleWhitenStart(chan));
	for (i = 0; i < len; i++)
		packet[i] = reverseBits(packet[i]); // the byte order of the packet should be reversed as well
}



void sendADV(uint8_t channel)
{
	
	hal_nrf_set_rf_channel(chRf[channel]);//_radio.setChannel(RF24BLE::chRf[channel]);

//	UART0_SendStr("Tx Len:");
//	PrintInt16(_length);
//	UART0_SendStr("\r\n");
//
//	UART0_SendStr("tx channel");
//	PrintInt16(channel);
//	UART0_SendStr("\r\n");

	if(_length <= TX_PACKET_LEN)
	{
		hal_nrf_write_tx_payload_noack(_packet_coded[channel],_length);//_radio.startWrite(_packet, _length,false);
	}
	else
	{
		UART0_SendStr("_length > TX_PACKET_LEN !\r\n");
	}
}


void UART0_SendStr( char* str )
{
    uint8_t i;
    uint8_t size = strlen(str);
    for(i=0; i<size; i++)
    {
        hal_uart_putchar(*(str+i));
    }
}

void IoInit(void)
{
    //P0DIR = 0x00;
    //P1DIR = 0x00;

	P1DIR = ( 1<<5 ) | ( 1<<6 );    //p0.0 p0.1  input£¬others output
	P0DIR = 0;
	P1 = 0xff;
	P1CON = 0xD5;                   //Enable pull up for P0.0
	P1CON = 0xD6;                   //Enable pull up for P0.1
	P0 &= ~( 1<<2 );
	P0 &= ~( 1<<1 );  

}


void adc_init(void)		 //get volt of BAT
{
    hal_adc_set_input_channel(HAL_INP_VDD1_3);          //1/3 VDD
    hal_adc_set_reference(HAL_ADC_REF_INT);             //set REF int 1.2V
    hal_adc_set_input_mode(HAL_ADC_SINGLE);
    hal_adc_set_conversion_mode(HAL_ADC_SINGLE_STEP);
    hal_adc_set_sampling_rate(HAL_ADC_2KSPS);
    hal_adc_set_resolution(HAL_ADC_RES_12BIT);          //12 bit ADC
    hal_adc_set_data_just(HAL_ADC_JUST_RIGHT);
}

void set_timer_period(uint16_t period)
{
    if((period<10) && (period>65536))period = 32768;
    hal_rtc_start(false);
    hal_rtc_start(true);
    hal_rtc_set_compare_value(period - 1);
}


void RfCofig(void)
{
	uint8_t  TX_ADDRESS[4]  = {0x8e,0x89,0xBE,0xD6};
	TX_ADDRESS[0] = reverseBits(TX_ADDRESS[0]);
	TX_ADDRESS[1] = reverseBits(TX_ADDRESS[1]);
	TX_ADDRESS[2] = reverseBits(TX_ADDRESS[2]);
	TX_ADDRESS[3] = reverseBits(TX_ADDRESS[3]);

    RFCKEN = 1;


    //BLE
	hal_nrf_close_pipe(HAL_NRF_ALL);
	hal_nrf_open_pipe(HAL_NRF_PIPE0,false);//	_radio.setAutoAck(false);
	hal_nrf_set_operation_mode(HAL_NRF_PTX);
	hal_nrf_set_rf_channel(chRf[0]);
	hal_nrf_set_datarate(HAL_NRF_1MBPS);//	_radio.setDataRate(RF24_1MBPS);
	hal_nrf_set_output_power(RF_POWER);//	_radio.setPALevel(RF24_PA_MAX);
	hal_nrf_set_crc_mode(HAL_NRF_CRC_OFF);//	_radio.disableCRC();
	hal_nrf_set_address_width(HAL_NRF_AW_4BYTES);//	_radio.setAddressWidth(4);
	hal_nrf_enable_dynamic_payload(false);
	hal_nrf_set_address(HAL_NRF_TX,TX_ADDRESS);//	_radio.openWritingPipe(address);
	hal_nrf_set_auto_retr(0,0);//	_radio.setRetries(0, 0);	
	hal_nrf_set_power_mode(HAL_NRF_PWR_UP);//	_radio.powerUp();

    RF = 1;
    EA = 1;
}

void mcu_init(void)
{
    hal_rtc_start(false);
    hal_clklf_set_source(HAL_CLKLF_RCOSC32K);           // Use 32.768KHz RC

    hal_rtc_set_compare_mode(HAL_RTC_COMPARE_MODE_0);   // Use 32 KHz timer mode 0
    set_timer_period(TAG_TIME);	                        // Set the RTC2 time£¬card sleep time
    hal_clk_set_16m_source(HAL_CLK_XOSC16M);            // Always run on 16MHz crystal oscillator
    hal_clk_regret_xosc16m_on(0);                       // Keep XOSC16M off in register retention

    hal_rtc_start(true);

    while((CLKLFCTRL&0x80)==0x80);	                    // Wait for the 32kHz to startup (change phase)
    while((CLKLFCTRL&0x80)!=0x80);
}

void Assemble_Data(void)
{
	uint8_t i;

	P1 |= ( 1<<5 ) | ( 1<<6 );  //P1.5 = 1; P1.6 = 1
	if( !( P1 & ( 1<<5 ) ) )    //check P1.5
	{
		TxPayload[0] = 2;//FUNCTION_CODE
	}
	else if( !( P1 & ( 1<<6 ) ) )    //Check P1.6
	{
		TxPayload[0] = 3;//FUNCTION_CODE
	}
	else
	{
		TxPayload[0] = 0;//FUNCTION_CODE
	}

    TxPayload[1] = TAG_ID;
    TxPayload[2] = CellVoltageH;
    TxPayload[3] = CellVoltageL;

	fill_crc(TxPayload,TX_PAYLOAD_LEN);

	setPhone(ANDROID);
	setMAC(MY_MAC_0, MY_MAC_1, MY_MAC_2, MY_MAC_3, MY_MAC_4, MY_MAC_5);
		
	setData(TxPayload, TX_PAYLOAD_LEN);

	for(i=0; i<TX_CH_NUMBER; i++)
	{
		_packet_coded[i][1] = _length-5;//subtract checksum bytes and the 2 bytes including the length byte and the first byte
		blePacketEncode(_packet_coded[i], _length, chLe[i]);
	}

//	UART0_SendStr("Assemble Len:");
//	PrintInt16(_length);
//	UART0_SendStr("\r\n");

}

void main()
{
    xdata   uint32_t  loopCount = ADC_TIME-1;
	uint8_t i;

    IoInit();
    mcu_init();

    hal_uart_init(UART_BAUD_9K6);  //UART£¬bps9600
    while(hal_clk_get_16m_source() != HAL_CLK_XOSC16M)
    {
    }

    hal_uart_putchar('a');

    adc_init();
    RfCofig();

#ifdef  USE_WDT
    hal_wdog_init(WDT_TIME);//watch dog 2s
#endif

    while(1)
    {
        loopCount++;

//        PrintInt16(loopCount);
//        UART0_SendStr("\r\n");

#ifdef  USE_WDT
        hal_wdog_restart(); //feed dog
#endif

        if(loopCount == ADC_TIME)    //Get volt of BAT every 5mins
        {
            hal_adc_start();           //ADC
            while( hal_adc_busy())     //wait ADC finish
                ;
            CellVoltageH = hal_adc_read_MSB(); //get ADC
            CellVoltageL = hal_adc_read_LSB();
            loopCount=0;
			Assemble_Data();
        }



//		UART0_SendStr("channel");
//		PrintInt16(CurrCH);
//		UART0_SendStr("\r\n");


        PWRDWN = 0x04;    // power down
        PWRDWN = 0x00;


#ifdef  POWER_SAVE
		CurrCH++;
		if (CurrCH>2)
		{
			CurrCH = 0;
		}
	  	sendADV(CurrCH);
		CE_PULSE();	            //RF send
		radio_busy = true;
		while(radio_busy)		    //wait RF finish
			;
#else

		for(i=0; i<TX_CH_NUMBER; i++)
		{
			sendADV(i);

			CE_PULSE();	            //RF send
			radio_busy = true;
			while(radio_busy)		    //wait RF finish
				;
		}
#endif
    }
}

void rf_irq() interrupt INTERRUPT_RFIRQ
{
    uint8_t  irq_flags;

    irq_flags = hal_nrf_get_clear_irq_flags();

    if(irq_flags & (1<<HAL_NRF_RX_DR))
    {

        while(!hal_nrf_rx_fifo_empty())// Read payload
        {
//            PipeAndLen = hal_nrf_read_rx_payload(RxPayload);
        }
        radio_busy = false;
    }

    if(irq_flags & ((1<<HAL_NRF_TX_DS)))			// transimmter finish
    {
        radio_busy = false;
    }

    if(irq_flags & ((1<<HAL_NRF_MAX_RT)))			// re-transimmter
    {
        radio_busy = false;
        hal_nrf_flush_tx();
    }
}

void PrintInt16(uint16_t Counter)
{
    uint8_t onechar;

    onechar = Counter/10000%10+0x30;
    hal_uart_putchar(onechar);

    onechar = Counter/1000%10+0x30;
    hal_uart_putchar(onechar);

    onechar = Counter/100%10+0x30;
    hal_uart_putchar(onechar);

    onechar = Counter/10%10+0x30;
    hal_uart_putchar(onechar);

    onechar = Counter%10+0x30;
    hal_uart_putchar(onechar);
}

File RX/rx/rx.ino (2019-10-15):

/*************************user modify settings****************************/
byte addresses[6] = {0x55,0x56,0x57,0x58,0x59,0x60};// should be same with tx
unsigned char  HopCH[3] = {105,76,108};//Which RF channel to communicate on, 0-125. We use 3 channels to hop.should be same with tx
#define TIME_OUT_CLOSE_DOOR 5000		//ms
#define DATA_LENGTH 4					//use fixed data length 1-32
#define BUZZON 1000				//set lenght of the buzz
#define BUZZOFF 30000			//set interval of the buzz
/*****************************************************/



#include <SPI.h>
#include "RF24.h"
#include "printf.h"


/* Hardware configuration: Set up nRF24L01 radio on SPI bus plus pins 7 & 8 */
RF24 radio(7,8);
/**********************************************************/



unsigned long PackageCounter = 0;
unsigned char CurrCH = 0;
unsigned long LastChangeCHTime = 0;
unsigned long LastGetTime = 0;
unsigned long CurrTime = 0;
unsigned char GotData[DATA_LENGTH];
unsigned long Volt;   //unit: mV,

#define DOOR 10
bool DoorOnOff = false;
bool DoorLastOnOff = false;
unsigned char  DoorLastOnID = 0;

#define BUZZ 9
bool BuzzOnOff;
bool AlarmOnOff;



void setup()
{

    pinMode(DOOR, OUTPUT);

    Serial.begin(115200);
    Serial.println(F("RF24_WiFi_ID_Read"));
    printf_begin();



    radio.begin();
    radio.setPALevel(RF24_PA_MIN);
    radio.setAddressWidth(5);
    radio.setPayloadSize(4);
    radio.setDataRate(RF24_2MBPS); //RF24_250KBPS  //RF24_2MBPS     //RF24_1MBPS
    radio.setChannel(105);
    radio.setCRCLength(RF24_CRC_8); //RF24_CRC_8 for 8-bit or RF24_CRC_16 for 16-bit

    //Open a writing and reading pipe on each radio, with opposite addresses
    radio.openWritingPipe(addresses);
    radio.openReadingPipe(0,addresses);
    radio.closeReadingPipe(1);
    radio.closeReadingPipe(2);
    radio.closeReadingPipe(3);
    radio.closeReadingPipe(4);
    radio.closeReadingPipe(5);
    radio.setAutoAck(1,false);
    radio.setAutoAck(2,false);
    radio.setAutoAck(3,false);
    radio.setAutoAck(4,false);
    radio.setAutoAck(5,false);
    radio.setAutoAck(0,false);
    //Start the radio listening for data
    radio.startListening();
}

void loop()
{


    if( radio.available())
    {
        // Variable for the received timestamp
        while (radio.available())                                     // While there is data ready
        {
            radio.read( GotData, sizeof(unsigned long) );             // Get the payload
        }
        Volt=1.2*(GotData[DATA_LENGTH-2]*256+GotData[DATA_LENGTH-1])*3*1000/4096;

        LastGetTime = millis();
        PackageCounter ++;


        Serial.print(PackageCounter);
        Serial.print(" ");
        Serial.print(F("Get data "));
        for(char i=0; i<DATA_LENGTH ; i++)
        {
            printf("%d,",GotData[i]);
        }
        printf("Volt:%d ",Volt);
        printf("CH:%d\r\n",CurrCH);
    }


    CurrTime = millis();


    if (abs(CurrTime - LastChangeCHTime>1000))//RF_HOP
    {
        CurrCH++;
        if (CurrCH>2)
        {
            CurrCH = 0;
        }
        LastChangeCHTime = millis();
        radio.stopListening();
        radio.setChannel(HopCH[CurrCH]);
        radio.startListening();
    }



    if (
        (
            (
                (CurrTime>=LastGetTime)
                ?
                (CurrTime - LastGetTime<TIME_OUT_CLOSE_DOOR)
                :
                ((0xFFFFFFFF-LastGetTime)+CurrTime<TIME_OUT_CLOSE_DOOR)
            )
        )
        &&
        (
            LastGetTime!=0
        )
    )// millis() is stored in a long. it will overflow in 49 days. so a little complex here.

    {
        DoorOnOff = true;
        AlarmOnOff = true;
    }
    else
    {
        DoorOnOff = false;
        AlarmOnOff = false;
    }

    if ( Serial.available() )
    {

    }
    Door_task();
    Buzz_task();
} // Loop

void Door_task()
{
    if (DoorLastOnOff != DoorOnOff)//update relay when door status change
    {
        DoorLastOnOff = DoorOnOff;
        if(DoorOnOff)
        {
            printf("Open door. \r\n");
            digitalWrite(DOOR, HIGH);
        }
        else
        {

            printf("Close door  \r\n");
            digitalWrite(DOOR, LOW);
        }
    }
}


void Buzz_task()
{

    static signed int BuzzOn;
    static signed int BuzzOff;
    if (AlarmOnOff)
    {
        if (BuzzOnOff)
        {
            BuzzOn++;
            if (BuzzOn > BUZZON)
            {
                BuzzOnOff = false;
                BuzzOn = 0;
            }
            else
            {
                BuzzOnOff = true;
            }
        }
        else
        {
            BuzzOff++;
            if (BuzzOff > BUZZOFF)
            {
                BuzzOnOff = true;
                BuzzOff = 0;
            }
            else
            {
                BuzzOnOff = false;
            }
        }
    }
    else
    {
        BuzzOn = 0;
        BuzzOff = 0;
        BuzzOnOff = false;
    }

    if (BuzzOnOff)
    {
        digitalWrite(BUZZ, HIGH);
    }
    else
    {
        digitalWrite(BUZZ, LOW);
    }
}

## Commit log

2017-08-04 add power cal
2017-08-05 3.3v for PA
2017-08-07 add 315mhz
    [rx.brd, rx_315mhz.brd, rx_315mhz.sch]
2017-08-09 web prepare
    [rx.brd]
2017-08-12 pcb_out,arduino struct
    [rx_315mhz.brd, rx_out.brd]
2017-09-03 tag with key
    [hal_adc.obj, hal_clk.obj, hal_delay.obj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]
2017-09-19 new bike
    [tag_key-v1.brd, tag_key-v1.sch]
2018-04-05 rc toy and power monitor
2018-04-22 315 command miss;charge mode amp
2018-11-13 ac control
    [CPPLINT.cfg]
2020-02-29 led unit
    [untitled.GBL, untitled.GBO, untitled.GBS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]
2020-03-12 led unit use u8g2
2020-03-17 sliding door distance
    [CPPLINT.cfg]
2020-03-23 LED_Unit CleanUp

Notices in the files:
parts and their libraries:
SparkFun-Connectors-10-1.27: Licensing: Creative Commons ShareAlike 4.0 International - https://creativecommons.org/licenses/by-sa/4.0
